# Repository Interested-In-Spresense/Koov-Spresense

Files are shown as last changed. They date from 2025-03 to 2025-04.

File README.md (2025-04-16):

# SpresenseでKOOVを動かすプロジェクト！

使わなくなってしまった子供たちのKOOVキットをSpresense(Arduino)で動かして、活用しようとするプロジェクト。<br>
下記の免責事項にご了承の方であれば、商業利用も含み自由にお使いくださって構いません。

## 免責事項

本リポジトリに含まれるコードおよび回路図は、個人的な学習・研究目的で提供されており、商用利用を目的としていません。
これらの内容は、正確性、信頼性、または動作保証について一切の保証を行いません。使用者は、自己の責任において本リポジトリのコードおよび回路図を使用するものとします。

### 注意事項

- 本リポジトリに含まれる回路図やコードの動作は、環境や実装条件によって異なる場合があります。使用前に十分なテストを行ってください。
- 万が一、使用に起因する損害や問題が発生した場合、リポジトリの管理者は一切の責任を負いません。

## ライセンス

本コードおよび回路図は、Creative Commons CC0 1.0 Public Domain Dedication)ライセンスの下で公開されています。

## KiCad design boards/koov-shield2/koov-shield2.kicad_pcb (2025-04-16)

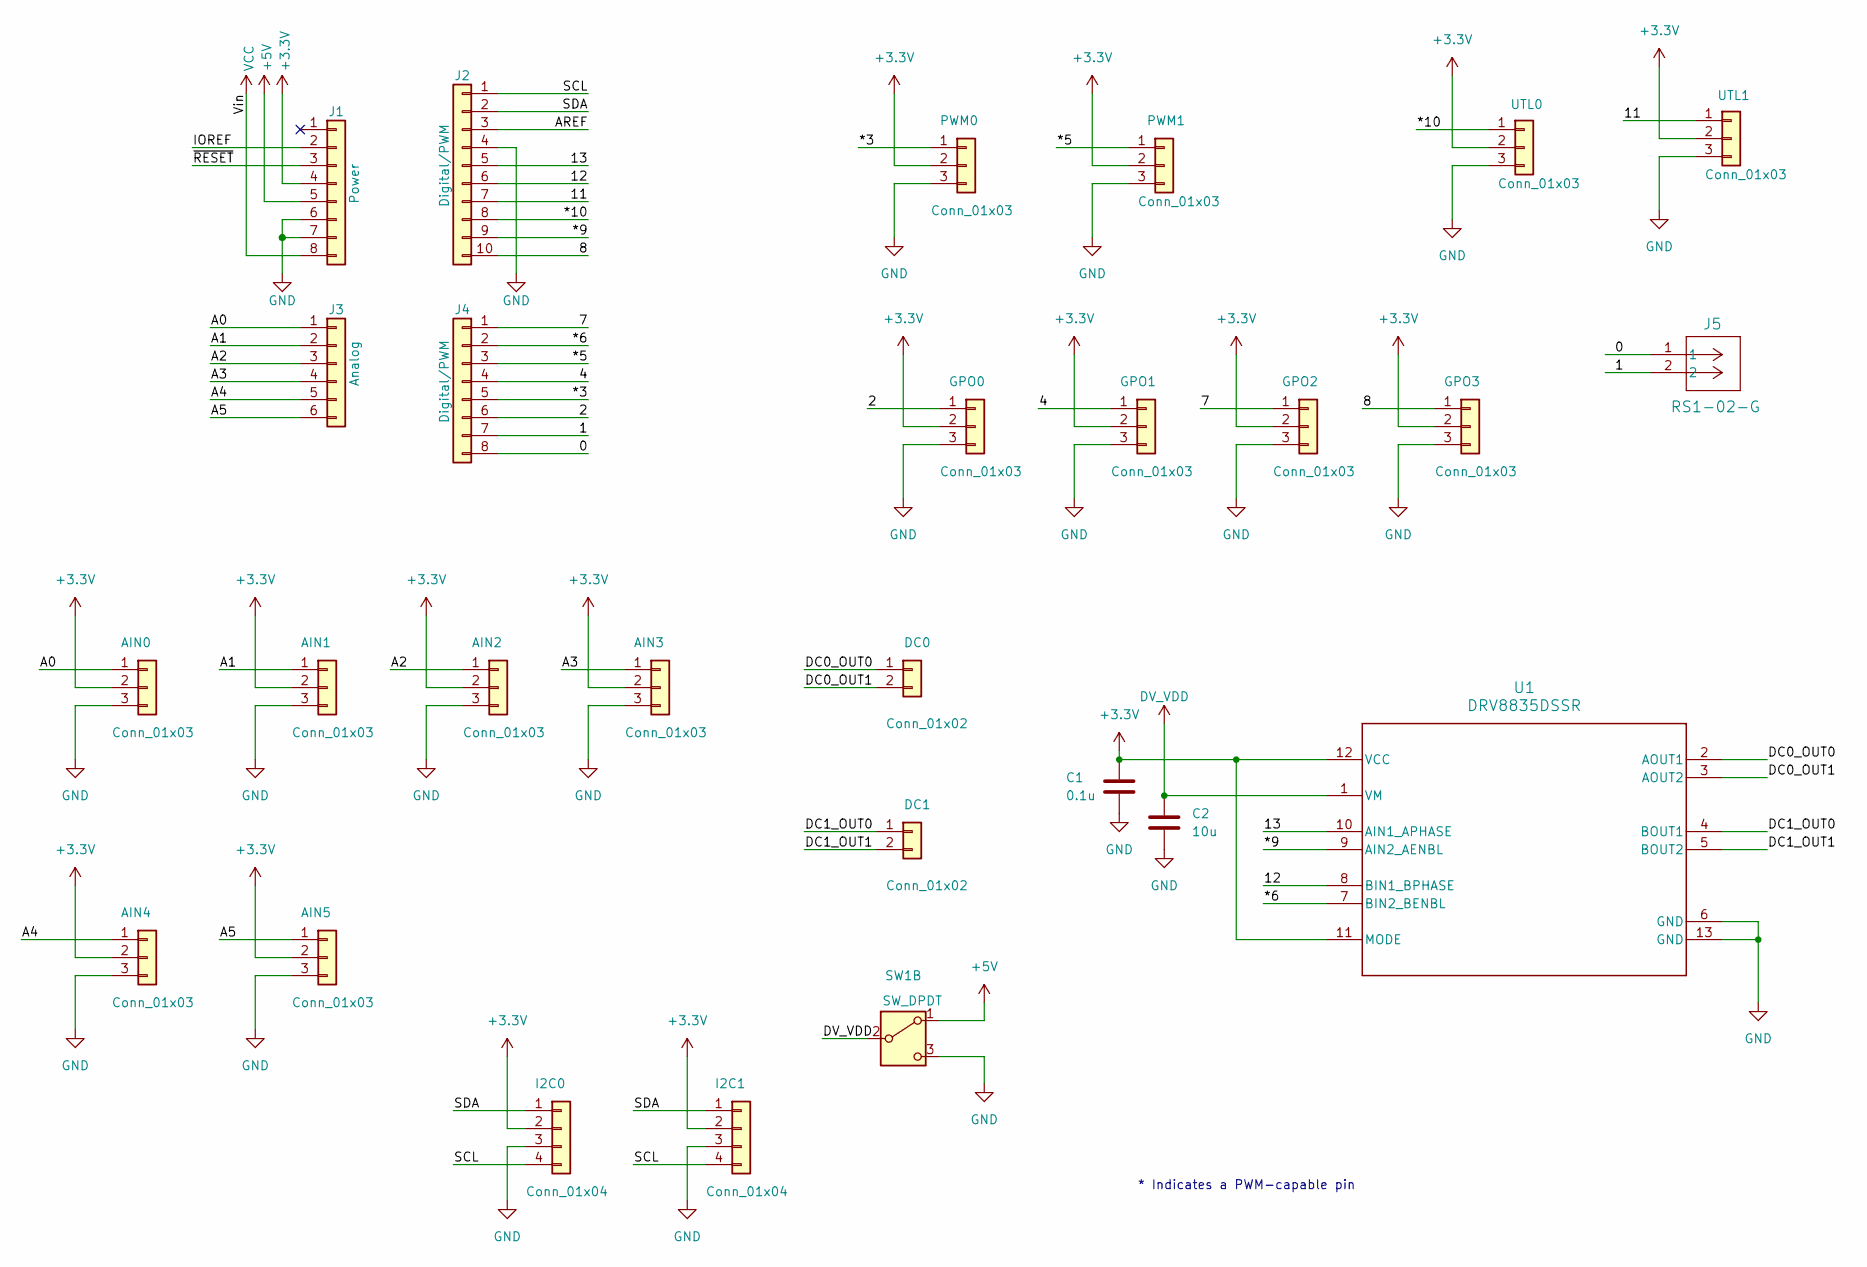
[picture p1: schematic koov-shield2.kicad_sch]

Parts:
AIN0, AIN1, AIN2, AIN3, AIN4, AIN5: Conn_01x03; PinHeader_1x03_P2.54mm_Vertical
C1: 0.1u; C_0402_1005Metric_Pad0.74x0.62mm_HandSolder
C2: 10u; C_0603_1608Metric_Pad1.08x0.95mm_HandSolder
DC0, DC1: Conn_01x02; PinHeader_1x02_P2.54mm_Vertical
GPO0, GPO1, GPO2, GPO3: Conn_01x03; PinHeader_1x03_P2.54mm_Vertical
I2C0, I2C1: Conn_01x04; PinHeader_1x04_P2.54mm_Vertical
J1: Power; PinHeader_1x08_P2.54mm_Vertical
J2: Digital/PWM; PinHeader_1x10_P2.54mm_Vertical
J3: Analog; PinHeader_1x06_P2.54mm_Vertical
J4: Digital/PWM; PinHeader_1x08_P2.54mm_Vertical
J5: RS1-02-G; CONN_RS1-02-G_ADM
PWM0, PWM1: Conn_01x03; PinHeader_1x03_P2.54mm_Vertical
SW1: SW_DPDT; AKIZUKI-SS-12D00G3
U1: DRV8835DSSR; DSS0012A
UTL0, UTL1: Conn_01x03; PinHeader_1x03_P2.54mm_Vertical

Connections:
+3.3V: AIN0.2, AIN1.2, AIN2.2, AIN3.2, AIN4.2, AIN5.2, C1.1, GPO0.2, GPO1.2, GPO2.2, GPO3.2, I2C0.2, I2C1.2, J1.4, PWM0.2, PWM1.2, U1.11 (MODE), U1.12 (VCC), UTL0.2, UTL1.2
+5V: J1.5, SW1.1 (A)
/0: J4.8, J5.1
/1: J4.7, J5.2
/2: GPO0.1, J4.6
/4: GPO1.1, J4.4
/7: GPO2.1, J4.1
/8: GPO3.1, J2.10
/11: J2.7, UTL1.1
/12: J2.6, U1.8 (BIN1_BPHASE)
/13: J2.5, U1.10 (AIN1_APHASE)
/*3: J4.5, PWM0.1
/*5: J4.3, PWM1.1
/*6: J4.2, U1.7 (BIN2_BENBL)
/*9: J2.9, U1.9 (AIN2_AENBL)
/*10: J2.8, UTL0.1
/A0: AIN0.1, J3.1
/A1: AIN1.1, J3.2
/A2: AIN2.1, J3.3
/A3: AIN3.1, J3.4
/A4: AIN4.1, J3.5
/A5: AIN5.1, J3.6
/AREF: J2.3
/DC0_OUT0: DC0.1, U1.2 (AOUT1)
/DC0_OUT1: DC0.2, U1.3 (AOUT2)
/DC1_OUT0: DC1.1, U1.4 (BOUT1)
/DC1_OUT1: DC1.2, U1.5 (BOUT2)
/DV_VDD: C2.1, SW1.2 (B), U1.1 (VM)
/IOREF: J1.2
/SCL: I2C0.4, I2C1.4, J2.1
/SDA: I2C0.1, I2C1.1, J2.2
/~RESET: J1.3
GND: AIN0.3, AIN1.3, AIN2.3, AIN3.3, AIN4.3, AIN5.3, C1.2, C2.2, GPO0.3, GPO1.3, GPO2.3, GPO3.3, I2C0.3, I2C1.3, J1.6, J1.7, J2.4, PWM0.3, PWM1.3, SW1.3 (C), U1.6 (GND), U1.13 (GND), UTL0.3, UTL1.3
VCC: J1.8

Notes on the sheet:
* Indicates a PWM-capable pin

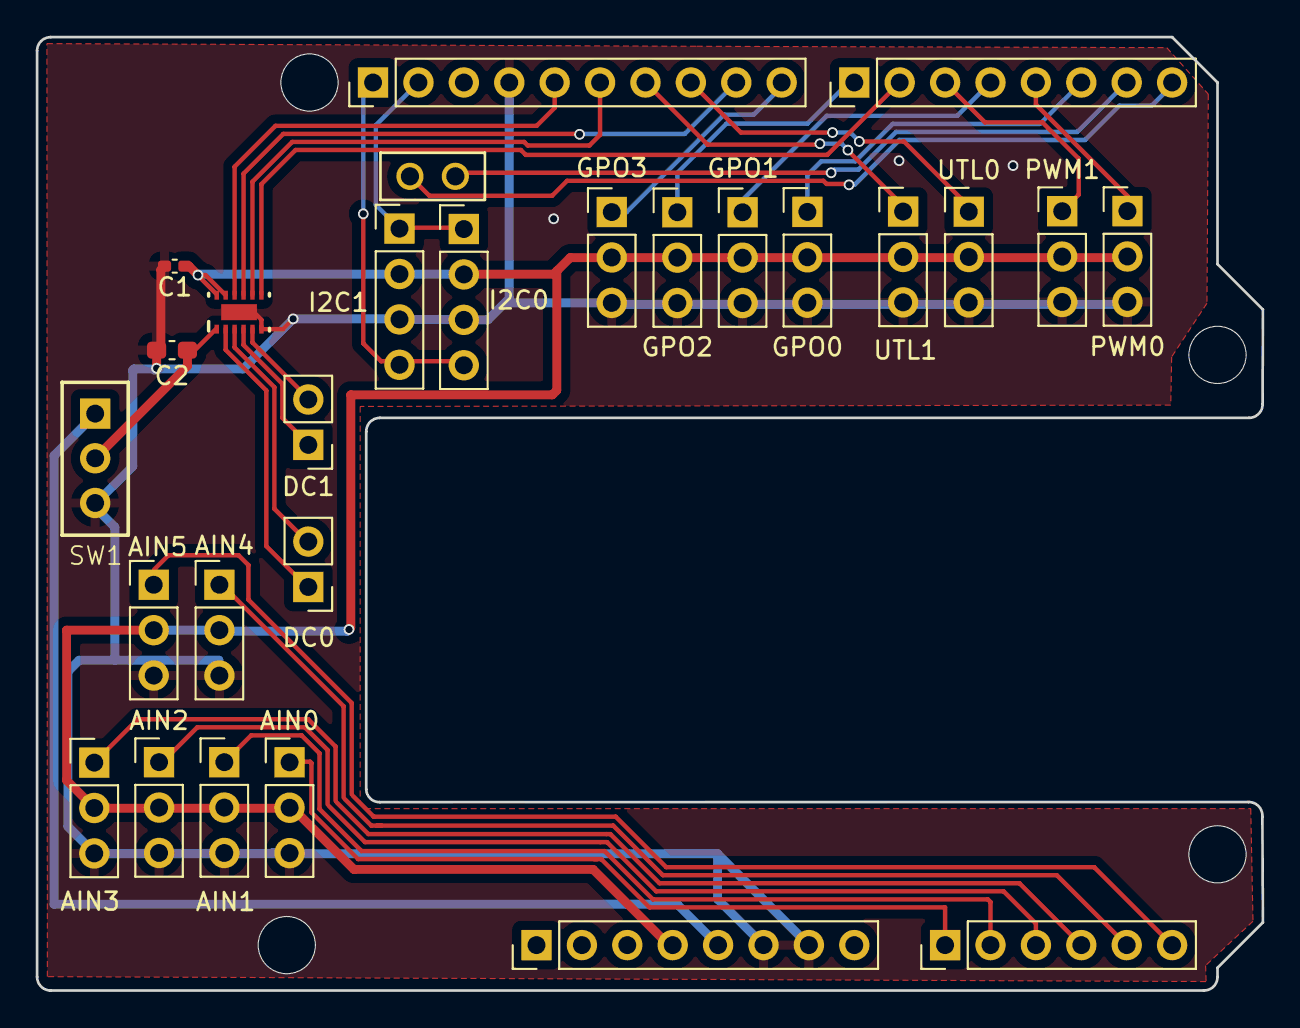
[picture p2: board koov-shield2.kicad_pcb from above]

Board: 2 copper layers, 68.6 x 53.3 mm, 31 parts (0 on the bottom side), 30 nets.

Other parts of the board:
MH1, MH2, MH3, MH4: MountingHole_3.2mm

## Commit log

2025-02-09 Add board design.
    [koov-shield3.kicad_pcb, koov-shield3.kicad_sch]
2025-02-21 Correct DC motor connector position.
    [koov-shield3.kicad_pcb]
2025-03-11 Support reverse-insertion-proof.
    [koov-shield3.kicad_pcb, koov-shield3.kicad_sch]
2025-03-11 Add a circuit that is designed for reflow soldering.
    [koov-shield2.kicad_pcb, koov-shield2.kicad_sch]
2025-03-12 Wiring UARTs to the unused connector.
    [koov-shield2.kicad_pcb, koov-shield2.kicad_sch, koov-shield3.kicad_pcb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]
2025-04-16 fix swirch miss.
    [koov-shield2.kicad_pcb, koov-shield2.kicad_sch]
